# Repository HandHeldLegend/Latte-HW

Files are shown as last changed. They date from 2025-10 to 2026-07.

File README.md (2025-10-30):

# Latte Project
This is the official Github page for project Latte from Hand Held Legend.

## Software and PCB License
<br />This firmware and PCB model are licensed under a <a rel="license" href="http://creativecommons.org/licenses/by-nc-sa/3.0/">Creative Commons Attribution-NonCommercial-ShareAlike 3.0 Unported License</a>.

## 3D Models License

<br />The 3D shell, buttons, and other associated models are licensed under a <a rel="license" href="http://creativecommons.org/licenses/by/4.0/">Creative Commons Attribution 4.0 International License</a>.

## Attributions

Resources Cross-Referenced for shell shape:
- 3D Scans by Wesk

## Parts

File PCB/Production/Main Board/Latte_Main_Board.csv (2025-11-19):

Reference | Qty | Value | Datasheet | Footprint | Manufacturer | MPN | DNP | LCSC | Description
C3,C4,C5,C6,C7,C8,C17,C18,C19,C29,C30,C31,C32,C33,C34,C35,C36,C37,C38 | 19 | 100n | ~ | Capacitor_SMD:C_0201_0603Metric | muRata | GRM033R61A104KE15D |  | C76934 | 10V 100nF X5R ±10% 0201 Ceramic Capacitors RoHS
C23,C39,C40,C41 | 4 | 4.7u | ~ | Capacitor_SMD:C_0402_1005Metric | Samsung Electro-Mechanics | CL05A475KP5NRNC |  | C368809 | 10V 4.7uF X5R ±10% 0402 Ceramic Capacitors RoHS
L1 | 1 | 3.3u | https://abracon.com/datasheets/AOTA-B201610S3R3-101-T.pdf | hhl:L_pol_2016 | Abraco LLC | AOTA-B201610S3R3-101-T |  | C42411119 | 0806 POLARIZED Fixed Inductors RoHS
R11 | 1 | 33 | ~ | Resistor_SMD:R_0201_0603Metric | YAGEO | RC0201FR-0733RL |  | C295794 | Resistor
SW1,SW2,SW3,SW4,SW5,SW6,SW7,SW8 | 8 | SW_Push | https://www.lcsc.com/datasheet/C221725.pdf | hhl:KSC-TE | C&K | KSC201J LFS |  | C221725 | Soft 160gf actuator, 3.5mm height tactile button IP67
SW9 | 1 | 1TS026A-1000-0550 | https://datasheet.lcsc.com/lcsc/2201131300_HYP--Hongyuan-Precision-1TS026A-1000-0550-CT_C913778.pdf | hhl:1TS026A-1000-0550 |  | 1TS026A-1000-0550 |  | C913778 | 50mA 2.6mm 100MΩ 200,000 Times 12V 100gf 1.6mm 0.55mm Round Button Standing paste SPST SMD,1.6x2.6mm Tactile Switches ROHS
U1,U3,U6,U7,U8,U9,U10,U11 | 8 | HAL4395 | https://www.lcsc.com/datasheet/C49165022.pdf | hhl:SOT-23-5L | Hallwee | HAL4395SO5 |  | C49165022 | SOT-23-5L Linear, Compass (ICs) ROHS
U2 | 1 | RP2350_80QFN |  | hhl:RP2350-QFN-80-1EP_10x10_P0.4mm_EP3.4x3.4mm_ThermalVias | Raspberry Pi | RP2354B |  | C39843328 | QFN-80-EP(10x10) Microcontrollers RoHS
R1,R15,R26,R27 | 4 | 1k | ~ | Resistor_SMD:R_0201_0603Metric | YAGEO | RC0201FR-071KL |  | C138165 | Resistor
C1,C2 | 2 | 15pF | ~ | Capacitor_SMD:C_0402_1005Metric | YAGEO | CC0402FRNPO9BN150 |  | C326803 | Unpolarized capacitor
C9,C10,C24,C25,C26,C27 | 6 | 100nF | ~ | Capacitor_SMD:C_0201_0603Metric | Samsung Electro-Mechanics | CL03A104KQ3NNNC |  | C160831 | Unpolarized capacitor
C11,C12,C13,C14 | 4 | 1uF | ~ | Capacitor_SMD:C_0201_0603Metric | Murata Electronics | GRM033R60J105KEA2D |  | C76929 | Unpolarized capacitor
D1,D2,D3,D4,D5,D6 | 6 | M7C | ~ | Diode_SMD:D_SOD-523 | LGE | B5819WT |  | C5364321 | Schottky diode
J1,J2 | 2 | SM02B-SURS-TF_LF__SN_ |  | hhl:JST_SM02B-SURS-TF_LF__SN_ | JST | SM02B-SURS-TF(LF)(SN) |  | C566239 | HD Rumble Connector
J3,J5 | 2 | Molex 505110-0892 | ~ | hhl:5051100892 | MOLEX | 505110-0892 |  | C5902847 | Generic connector, single row, 01x08, script generated
J4,J6 | 2 | Molex 505110-0592 | ~ | hhl:5051100592 | MOLEX | 505110-0592 |  | C3168457 | Generic connector, single row, 01x05, script generated
J9 | 1 | Molex 505110-1792 | ~ | hhl:5051101792 | MOLEX | 505110-1792 |  | C6819458 | Generic connector, single row, 01x17, script generated
Q1,Q2 | 2 | MMBT2222A | https://assets.nexperia.com/documents/data-sheet/MMBT2222A.pdf | Package_TO_SOT_SMD:SOT-23 | JSMSEMI | MMBT2222A |  | C916372 | 600mA Ic, 40V Vce, NPN Transistor, SOT-23
R2,R7,R8,R12,R13,R14,R16,R17,R18,R19,R20,R21,R22,R23,R24,R25,R28,R29,R30,R31 | 20 | 100R | ~ | Resistor_SMD:R_0201_0603Metric | YAGEO | RC0201FR-07100RL |  | C77623 | Resistor
R3,R4 | 2 | 27R | ~ | Resistor_SMD:R_0201_0603Metric | YAGEO | RC0201FR-0727RL |  | C273268 | Resistor
R5,R6 | 2 | 10k | ~ | Resistor_SMD:R_0201_0603Metric | YAGEO | RC0201FR-0710KL |  | C106225 | Resistor
R9,R10 | 2 | 10R | ~ | Resistor_SMD:R_0201_0603Metric | YAGEO | RC0201FR-0710RL |  | C106226 | Resistor
RGB1,RGB2,RGB3,RGB4,RGB5,RGB6,RGB7,RGB8,RGB9,RGB10,RGB11,RGB12 | 12 | SK6805-EC-10 | https://cdn-shop.adafruit.com/product-files/5849/SK6805-EC10-000_REV.01_EN.pdf | hhl:SK6805-EC-10 | OPSCO Optoelectronics | SK6805-EC-10 |  | C22394946 | RGB LED
U4,U5 | 2 | ST_LSM6 |  | hhl:LGA14 | STMicroelectronics | LSM6DSLTR |  | C126672 | Accelerometer gyroscope LGA-14(2.5x3) Accelerometers ROHS
Y1 | 1 | ABM8-272-T3 | ~ | Crystal:Crystal_SMD_3225-4Pin_3.2x2.5mm | Abracon LLC | ABM8-272-T3 |  | C20625731 | Four pin crystal, GND on pins 2 and 4

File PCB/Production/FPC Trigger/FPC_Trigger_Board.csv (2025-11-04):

Reference | Qty | Value | Datasheet | Footprint | Manufacturer | MPN | LCSC | DNP
C1,C2,C3,C4 | 4 | 100n | ~ | Capacitor_SMD:C_0201_0603Metric | muRata | GRM033R61A104KE15D | C76934
J1,J2 | 2 | Conn_01x05_Pin | ~ | hhl:505110-0592 Ribbon |  |  |  | DNP
U1,U2,U3,U4 | 4 | HAL4395 | https://www.lcsc.com/datasheet/C49165022.pdf | Package_TO_SOT_SMD:SOT-23-5 | Hallwee | HAL4395SO5 | C49165022

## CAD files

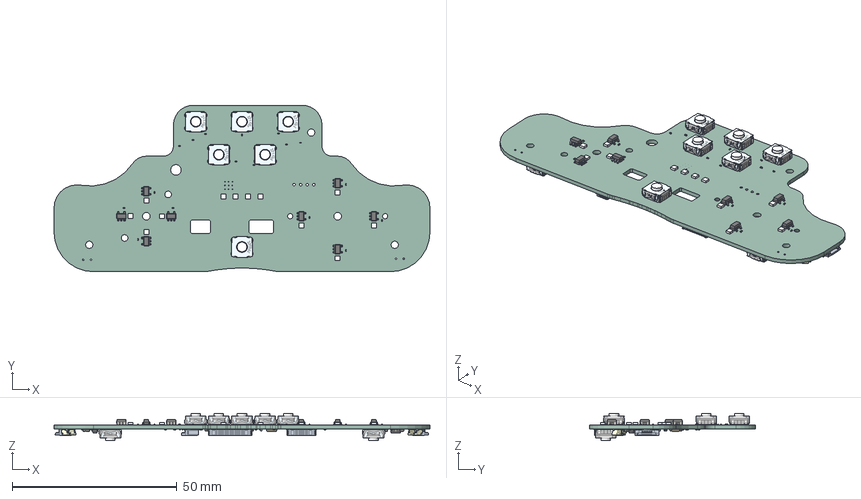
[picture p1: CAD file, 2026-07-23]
3D/Latte_Main_Board.step
114.0 x 50.5 x 8.33 mm
SK6805-EC15 x 12
R_0201_0603Metric x 31
C_0201_0603Metric x 29
KSC2TE01JLFS_PART1 x 8
SOT-23-5 x 8
SOT-23 x 2
D_SOD-523 x 6
C_0402_1005Metric x 6
SM02B-SURS-TF(LF)(SN) x 2
Crystal_SMD_3225-4Pin_3.2x2.5mm
Latte_Main_Board_PCB

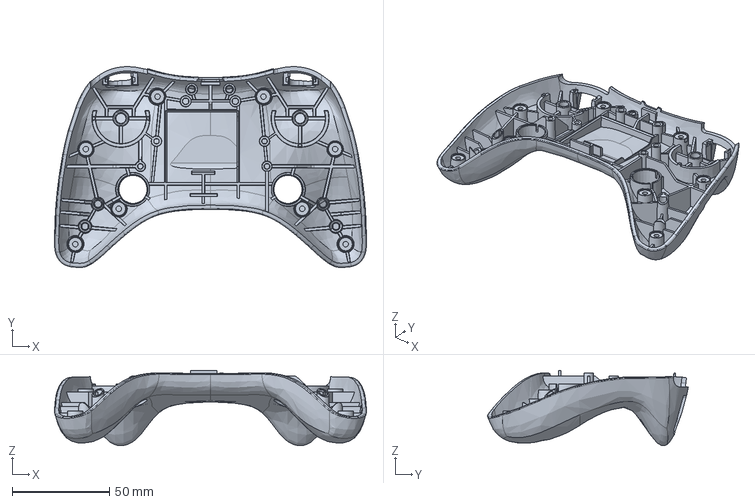
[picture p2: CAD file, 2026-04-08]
3D/STEP/Acrylic/PRO_LOWERSHELL.step
160.2 x 103.1 x 38.7 mm

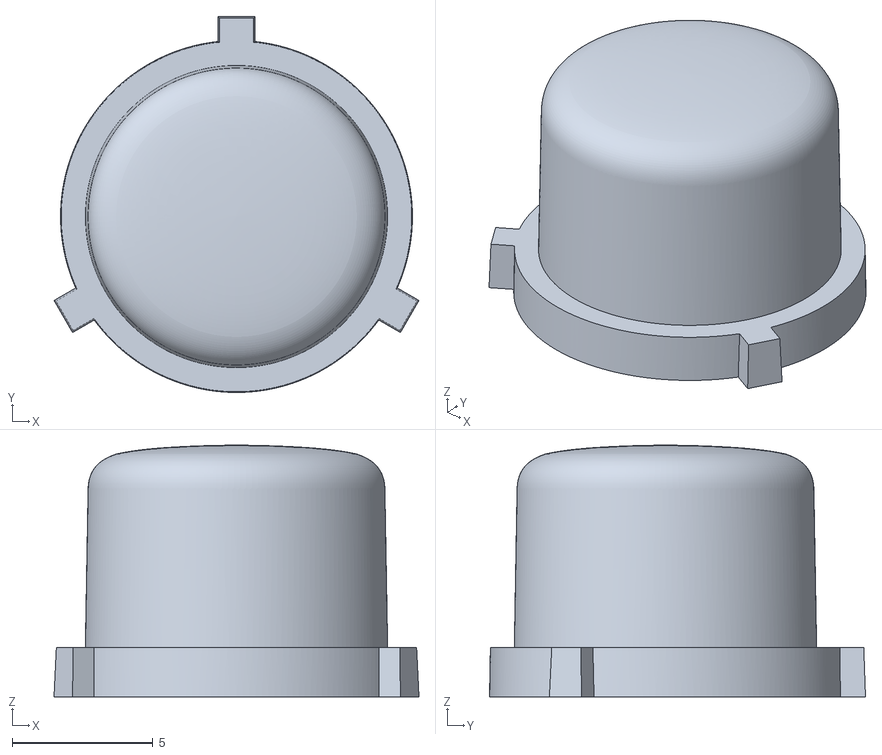
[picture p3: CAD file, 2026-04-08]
3D/STL/SEWN.stl
13.0 x 13.4 x 8.95

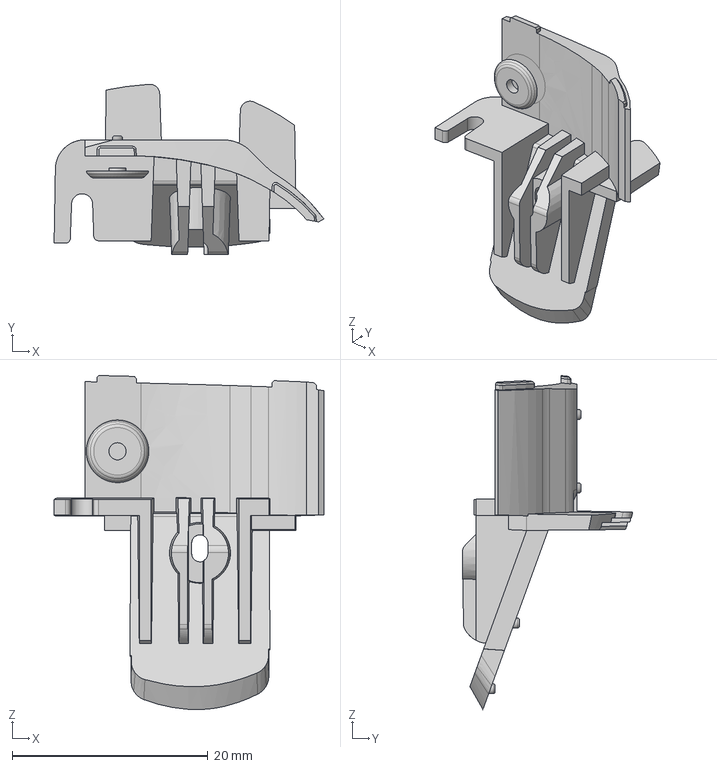
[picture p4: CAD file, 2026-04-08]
3D/STEP/Acrylic/PRO_RSUPPORT.step
27.5 x 17.4 x 34.1 mm

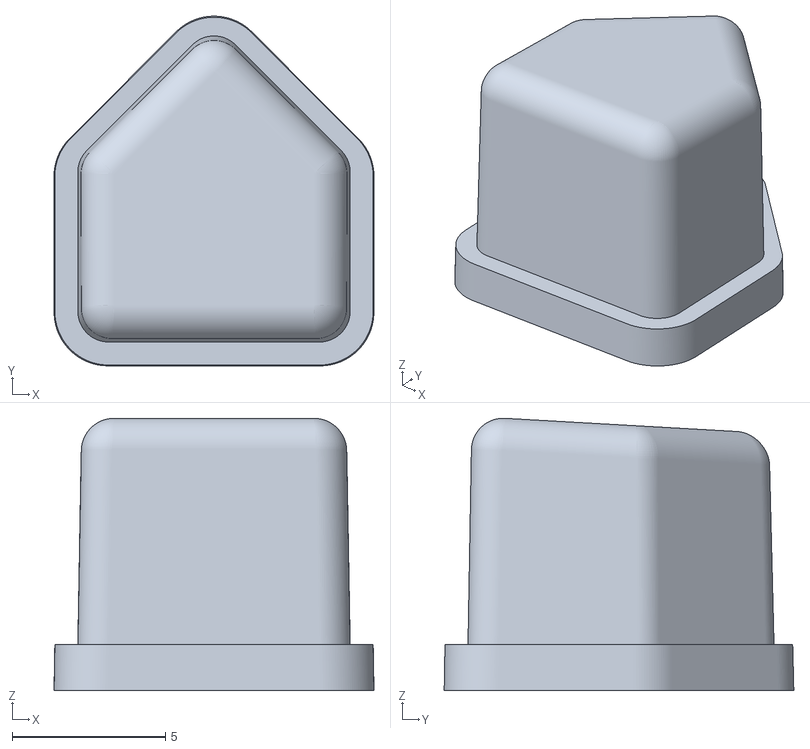
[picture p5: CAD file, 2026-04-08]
3D/STL/DPAD.stl
10.4 x 11.4 x 8.88

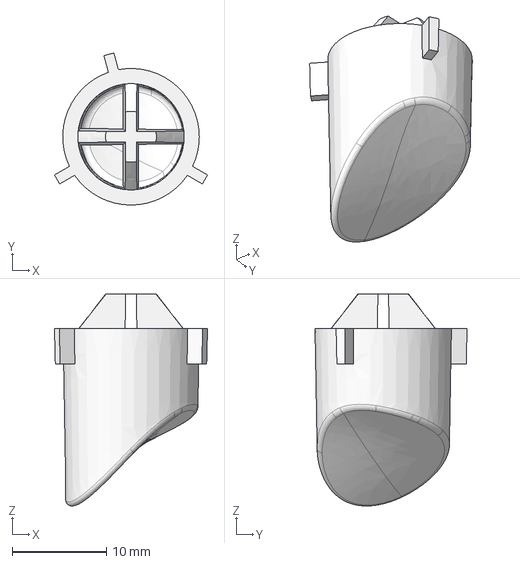
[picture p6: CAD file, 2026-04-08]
3D/STEP/Acrylic/PRO_GRIPBUTTONL.step
16.2 x 16.1 x 22.5 mm

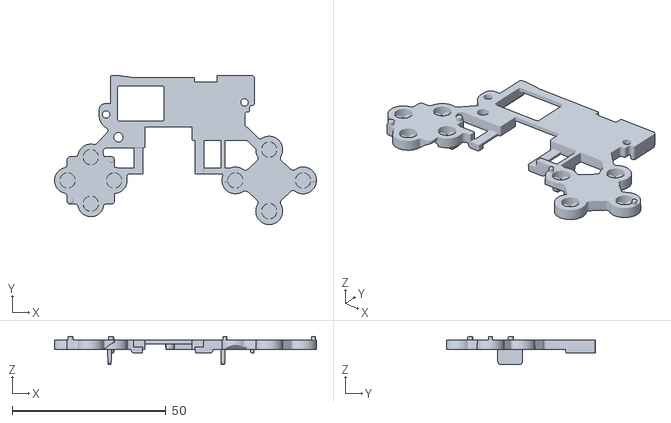
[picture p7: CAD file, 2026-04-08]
3D/STL/MIDFRAME.stl
85.2 x 48.5 x 9.21

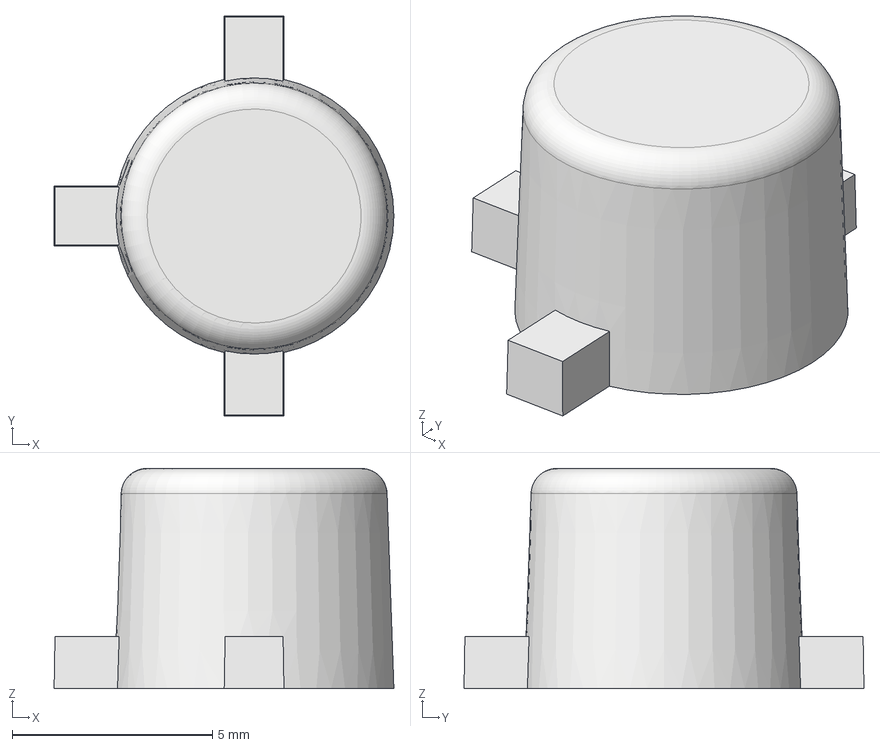
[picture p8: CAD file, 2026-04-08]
3D/STEP/Acrylic/PRO_MENU.step
8.49 x 9.99 x 5.50 mm

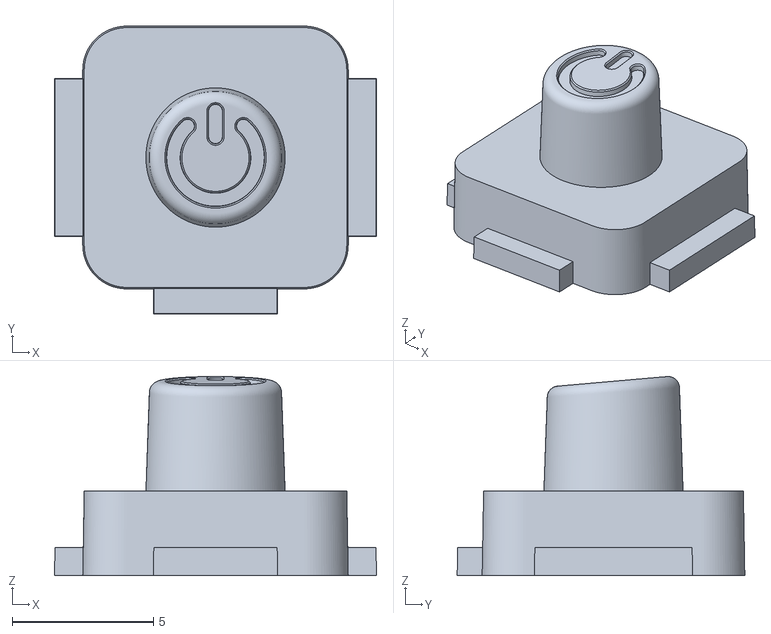
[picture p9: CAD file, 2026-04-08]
3D/STL/POWERBUTTON.stl
11.4 x 10.2 x 7.05

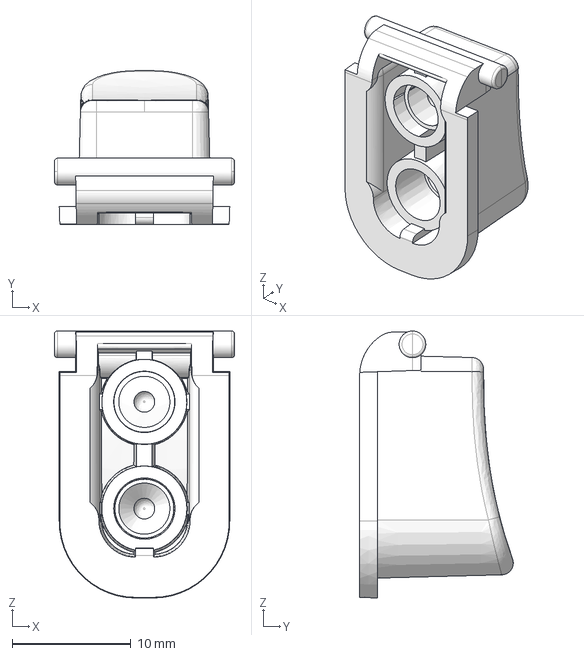
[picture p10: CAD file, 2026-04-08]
3D/STEP/Acrylic/PRO_TRIGGER.step
15.2 x 12.9 x 22.5 mm

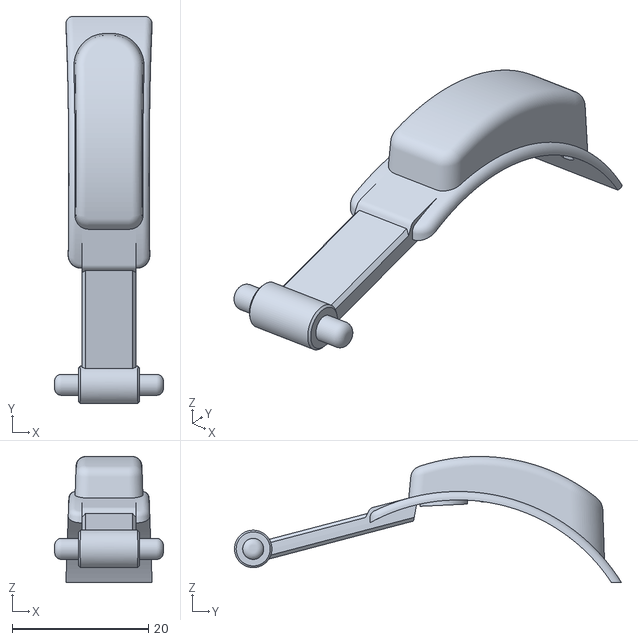
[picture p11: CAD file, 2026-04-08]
3D/STL/SHOULDER.stl
16.0 x 56.9 x 18.5

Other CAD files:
3D/STEP/Acrylic/PRO_DPAD.step
3D/STL/LSUPPORT.stl
3D/STEP/Acrylic/PRO_LSUPPORT.step
3D/STL/GRIPBUTTONR.stl
3D/STEP/Acrylic/PRO_GRIPBUTTONR.step
3D/STL/RSUPPORT.stl
3D/STEP/Acrylic/PRO_POWERBUTTON.step
3D/STEP/Acrylic/PRO_MIDFRAME.step
3D/STEP/Acrylic/PRO_PLAYERLIGHTS.step
3D/STEP/Acrylic/PRO_SEWN.step
3D/STEP/Acrylic/PRO_SHOULDER.step
3D/STEP/POM/ScrewPlateOctagon.step
3D/STEP/POM/ScrewPlateRound.step
3D/STL/GRIPBUTTONL.stl
3D/STL/MENU.stl
3D/STL/PLAYERLIGHTS.stl
3D/STL/SCREWPLATEOCTO.stl
3D/STL/SCREWPLATEROUND.stl
3D/STL/TRIGGER.stl

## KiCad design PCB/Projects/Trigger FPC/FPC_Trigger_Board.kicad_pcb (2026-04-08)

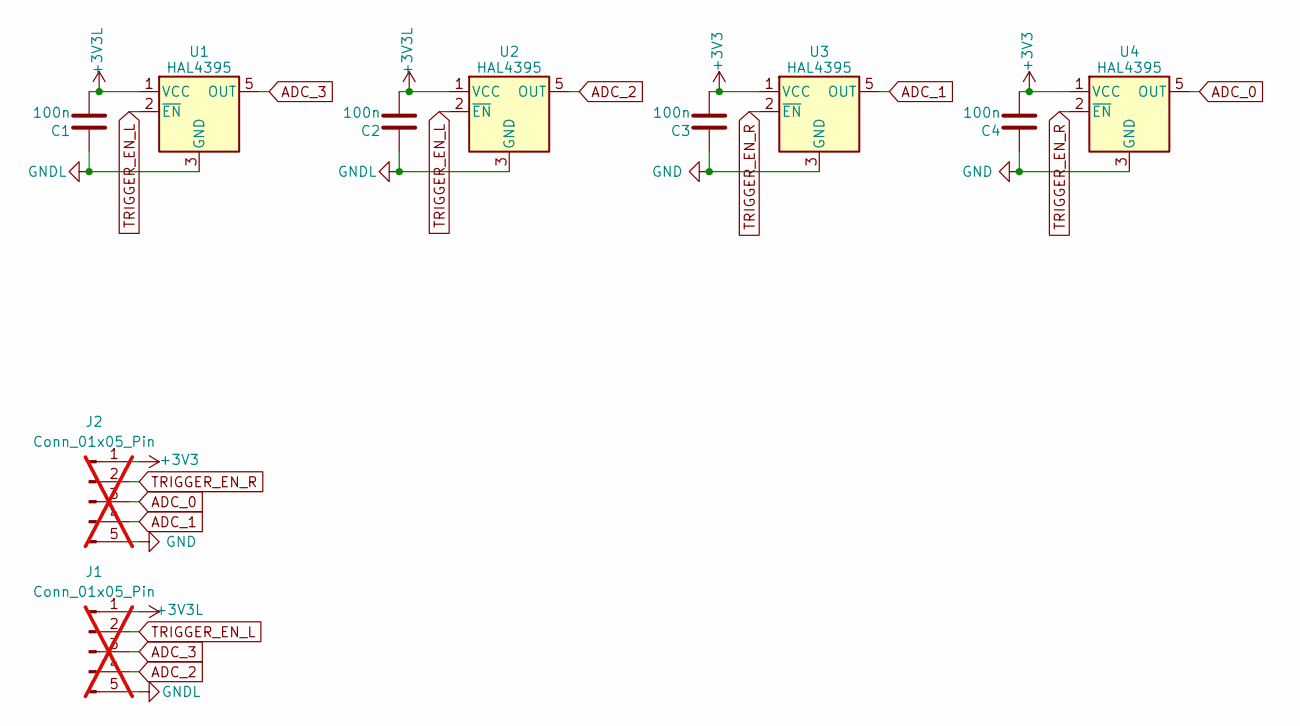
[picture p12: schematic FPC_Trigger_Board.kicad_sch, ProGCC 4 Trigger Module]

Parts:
C1, C2, C3, C4: 100n; C_0201_0603Metric; MPN GRM033R61A104KE15D; LCSC C76934
J1, J2: Conn_01x05_Pin; 505110-0592 Ribbon; not fitted
U1, U2, U3, U4: HAL4395; SOT-23-5L; MPN HAL4395SO5; LCSC C49165022

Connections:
+3V3: C3.2, C4.2, J2.1, U3.1 (VCC), U4.1 (VCC)
+3V3L: C1.2, C2.2, J1.1, U1.1 (VCC), U2.1 (VCC)
ADC_0: J2.3, U4.5 (OUT)
ADC_1: J2.4, U3.5 (OUT)
ADC_2: J1.4, U2.5 (OUT)
ADC_3: J1.3, U1.5 (OUT)
GND: C3.1, C4.1, J2.5, U3.3 (GND), U4.3 (GND)
GNDL: C1.1, C2.1, J1.5, U1.3 (GND), U2.3 (GND)
TRIGGER_EN_L: J1.2, U1.2 (~EN), U2.2 (~EN)
TRIGGER_EN_R: J2.2, U3.2 (~EN), U4.2 (~EN)

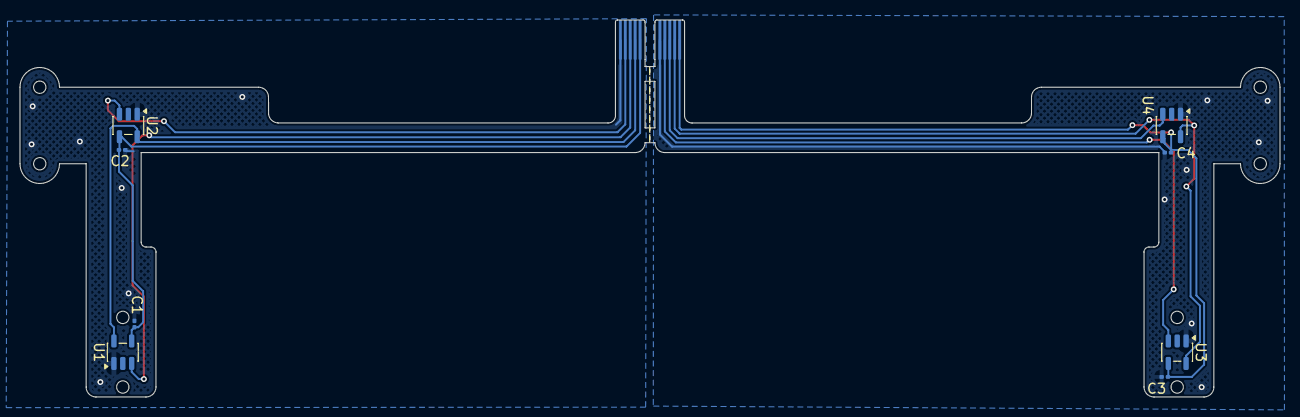
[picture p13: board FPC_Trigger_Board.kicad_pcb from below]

Board: 2 copper layers, 127.6 x 38.2 mm, 10 parts (8 on the bottom side), 10 nets.

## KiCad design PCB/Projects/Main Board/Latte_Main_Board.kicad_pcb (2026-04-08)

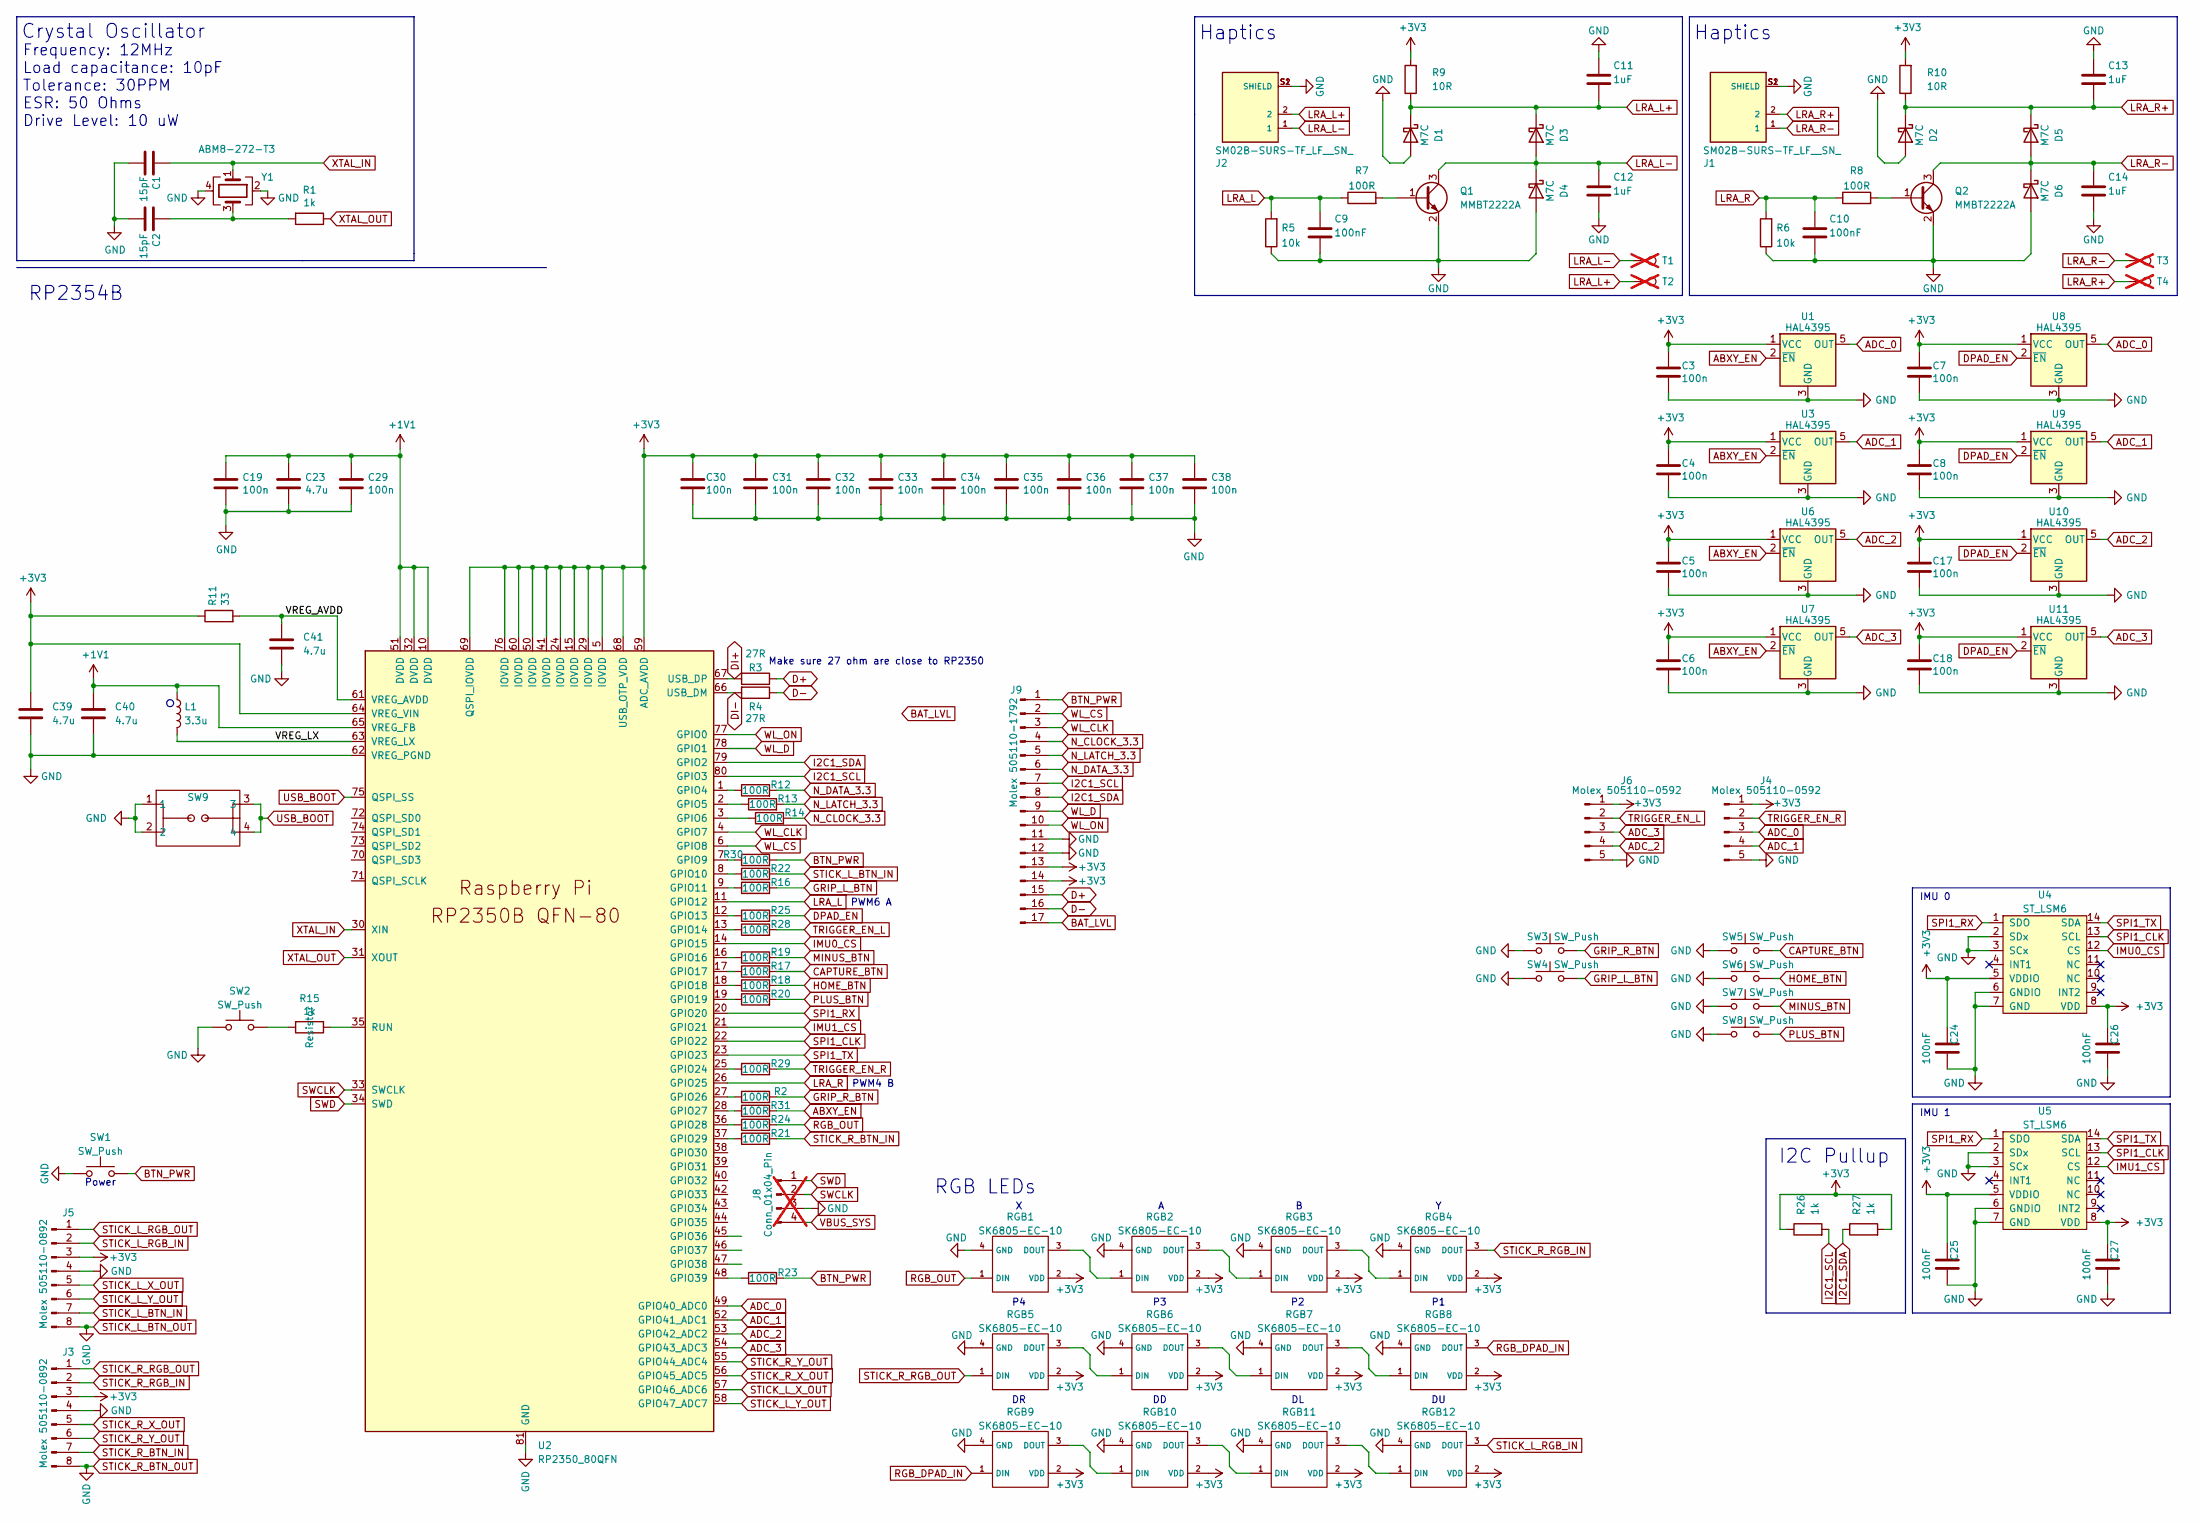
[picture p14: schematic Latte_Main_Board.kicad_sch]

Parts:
C1, C2: 15pF; C_0402_1005Metric; MPN CC0402FRNPO9BN150; LCSC C326803
C3, C4, C5, C6, C7, C8, C17, C18, C19, C29, C30, C31, C32, C33, C34, C35, C36, C37, C38: 100n; C_0201_0603Metric; MPN GRM033R61A104KE15D; LCSC C76934
C9, C10, C24, C25, C26, C27: 100nF; C_0201_0603Metric; MPN CL03A104KQ3NNNC; LCSC C160831
C11, C12, C13, C14: 1uF; C_0201_0603Metric; MPN GRM033R60J105KEA2D; LCSC C76929
C23, C39, C40, C41: 4.7u; C_0402_1005Metric; MPN CL05A475KP5NRNC; LCSC C368809
D1, D2, D3, D4, D5, D6: M7C; D_SOD-523; MPN B5819WT; LCSC C5364321
J1, J2: SM02B-SURS-TF_LF__SN_; JST_SM02B-SURS-TF_LF__SN_; PARTREV N/A; LCSC C566239
J3, J5: Molex 505110-0892; 5051100892; MPN 505110-0892; LCSC C5902847
J4, J6: Molex 505110-0592; 5051100592; MPN 505110-0592; LCSC C3168457
J8: Conn_01x04_Pin; PinHeader_1x04_P2.00mm_Vertical; not fitted
J9: Molex 505110-1792; 5051101792; MPN 505110-1792; LCSC C6819458
L1: 3.3u; L_pol_2016; MPN AOTA-B201610S3R3-101-T; LCSC C42411119
Q1, Q2: MMBT2222A; SOT-23; MPN MMBT2222A; LCSC C916372
R1, R15, R26, R27: 1k; R_0201_0603Metric; MPN RC0201FR-071KL; LCSC C138165
R2, R7, R8, R12, R13, R14, R16, R17, R18, R19, R20, R21, R22, R23, R24, R25, R28, R29, R30, R31: 100R; R_0201_0603Metric; MPN RC0201FR-07100RL; LCSC C77623
R3, R4: 27R; R_0201_0603Metric; MPN RC0201FR-0727RL; LCSC C273268
R5, R6: 10k; R_0201_0603Metric; MPN RC0201FR-0710KL; LCSC C106225
R9, R10: 10R; R_0201_0603Metric; MPN RC0201FR-0710RL; LCSC C106226
R11: 33; R_0201_0603Metric; MPN RC0201FR-0733RL; LCSC C295794
RGB1, RGB2, RGB3, RGB4, RGB5, RGB6, RGB7, RGB8, RGB9, RGB10, RGB11, RGB12: SK6805-EC-10; MPN SK6805-EC-10; LCSC C22394946
SW1, SW2, SW3, SW4, SW5, SW6, SW7, SW8: SW_Push; KSC-TE; MPN KSC201J LFS; LCSC C221725
SW9: 1TS026A-1000-0550; MPN 1TS026A-1000-0550; LCSC C913778
T1, T2, T3, T4: PinHeader_1x01_P1.00mm_Vertical; not fitted
U1, U3, U6, U7, U8, U9, U10, U11: HAL4395; SOT-23-5L; MPN HAL4395SO5; LCSC C49165022
U2: RP2350_80QFN; RP2350-QFN-80-1EP_10x10_P0.4mm_EP3.4x3.4mm_ThermalVias; MPN RP2354B; LCSC C39843328
U4, U5: ST_LSM6; LGA14; MPN LSM6DSLTR; LCSC C126672
Y1: ABM8-272-T3; Crystal_SMD_3225-4Pin_3.2x2.5mm; MPN ABM8-272-T3; LCSC C20625731

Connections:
+1V1: C19.1, C23.1, C29.1, C40.1, L1.1, U2.10 (DVDD), U2.32 (DVDD), U2.51 (DVDD), U2.65 (VREG_FB)
+3V3: C3.1, C4.1, C5.1, C6.1, C7.1, C8.1, C17.1, C18.1, C24.2, C25.2, C26.2, C27.2, C30.1, C31.1, C32.1, C33.1, C34.1, C35.1, C36.1, C37.1, C38.1, C39.1, J3.3, J4.1, J5.3, J6.1, J9.13, J9.14, R9.2, R10.2, R11.1, R26.1, R27.2, RGB1.2 (VDD), RGB2.2 (VDD), RGB3.2 (VDD), RGB4.2 (VDD), RGB5.2 (VDD), RGB6.2 (VDD), RGB7.2 (VDD), RGB8.2 (VDD), RGB9.2 (VDD), RGB10.2 (VDD), RGB11.2 (VDD), RGB12.2 (VDD), U1.1 (VCC), U2.5 (IOVDD), U2.15 (IOVDD), U2.24 (IOVDD), U2.29 (IOVDD), U2.41 (IOVDD), U2.50 (IOVDD), U2.59 (ADC_AVDD), U2.60 (IOVDD), U2.64 (VREG_VIN), U2.68 (USB_OTP_VDD), U2.69 (QSPI_IOVDD), U2.76 (IOVDD), U3.1 (VCC), U4.5 (VDDIO), U4.8 (VDD), U5.5 (VDDIO), U5.8 (VDD), U6.1 (VCC), U7.1 (VCC), U8.1 (VCC), U9.1 (VCC), U10.1 (VCC), U11.1 (VCC)
/VREG_AVDD: C41.1, R11.2, U2.61 (VREG_AVDD)
/VREG_LX: L1.2, U2.63 (VREG_LX)
ABXY_EN: R31.2, U1.2 (~EN), U3.2 (~EN), U6.2 (~EN), U7.2 (~EN)
ADC_0: J4.3, U1.5 (OUT), U2.49 (GPIO40_ADC0), U8.5 (OUT)
ADC_1: J4.4, U2.52 (GPIO41_ADC1), U3.5 (OUT), U9.5 (OUT)
ADC_2: J6.4, U2.53 (GPIO42_ADC2), U6.5 (OUT), U10.5 (OUT)
ADC_3: J6.3, U2.54 (GPIO43_ADC3), U7.5 (OUT), U11.5 (OUT)
BAT_LVL: J9.17
BTN_PWR: J9.1, R23.2, R30.2, SW1.2
CAPTURE_BTN: R17.2, SW5.2
D+: J9.15, R3.1
D-: J9.16, R4.1
DI+: R3.2, U2.67 (USB_DP)
DI-: R4.2, U2.66 (USB_DM)
DPAD_EN: R25.2, U8.2 (~EN), U9.2 (~EN), U10.2 (~EN), U11.2 (~EN)
GRIP_L_BTN: R16.2, SW4.2
GRIP_R_BTN: R2.2, SW3.2
HOME_BTN: R18.2, SW6.2
I2C1_SCL: J9.7, R26.2, U2.80 (GPIO3)
I2C1_SDA: J9.8, R27.1, U2.79 (GPIO2)
IMU0_CS: U2.14 (GPIO15), U4.12 (CS)
IMU1_CS: U2.21 (GPIO21), U5.12 (CS)
LRA_L: C9.1, R5.2, R7.1, U2.11 (GPIO12)
LRA_L+: C11.2, D1.1 (K), D3.1 (K), J2.2, R9.1, T2.1
LRA_L-: C12.1, D3.2 (A), D4.1 (K), J2.1, Q1.3 (C), T1.1
LRA_R: C10.1, R6.2, R8.1, U2.26 (GPIO25)
LRA_R+: C13.2, D2.1 (K), D5.1 (K), J1.2, R10.1, T4.1
LRA_R-: C14.1, D5.2 (A), D6.1 (K), J1.1, Q2.3 (C), T3.1
MINUS_BTN: R19.2, SW7.2
N_CLOCK_3.3: J9.4, R14.2
N_DATA_3.3: J9.6, R12.2
N_LATCH_3.3: J9.5, R13.2
unnamed: C2.1, R1.2, Y1.3
unnamed: Q1.1 (B), R7.2
unnamed: Q2.1 (B), R8.2
unnamed: R15.2, SW2.2
unnamed: RGB1.3 (DOUT), RGB2.1 (DIN)
unnamed: RGB2.3 (DOUT), RGB3.1 (DIN)
unnamed: RGB3.3 (DOUT), RGB4.1 (DIN)
unnamed: RGB5.3 (DOUT), RGB6.1 (DIN)
unnamed: RGB6.3 (DOUT), RGB7.1 (DIN)
unnamed: RGB7.3 (DOUT), RGB8.1 (DIN)
unnamed: RGB9.3 (DOUT), RGB10.1 (DIN)
unnamed: RGB10.3 (DOUT), RGB11.1 (DIN)
unnamed: RGB11.3 (DOUT), RGB12.1 (DIN)
unnamed: R12.1, U2.1 (GPIO4)
unnamed: R13.1, U2.2 (GPIO5)
unnamed: R14.1, U2.3 (GPIO6)
unnamed: R30.1, U2.7 (GPIO9)
unnamed: R22.1, U2.8 (GPIO10)
unnamed: R16.1, U2.9 (GPIO11)
unnamed: R25.1, U2.12 (GPIO13)
unnamed: R28.1, U2.13 (GPIO14)
unnamed: R19.1, U2.16 (GPIO16)
unnamed: R17.1, U2.17 (GPIO17)
unnamed: R18.1, U2.18 (GPIO18)
unnamed: R20.1, U2.19 (GPIO19)
unnamed: R29.1, U2.25 (GPIO24)
unnamed: R2.1, U2.27 (GPIO26)
unnamed: R31.1, U2.28 (GPIO27)
unnamed: R24.1, U2.36 (GPIO28)
unnamed: R21.1, U2.37 (GPIO29)
unnamed: R23.1, U2.48 (GPIO39)
unnamed: R15.1, U2.35 (RUN)
PLUS_BTN: R20.2, SW8.2
RGB_DPAD_IN: RGB8.3 (DOUT), RGB9.1 (DIN)
RGB_OUT: R24.2, RGB1.1 (DIN)
SPI1_CLK: U2.22 (GPIO22), U4.13 (SCL), U5.13 (SCL)
SPI1_RX: U2.20 (GPIO20), U4.1 (SDO), U5.1 (SDO)
SPI1_TX: U2.23 (GPIO23), U4.14 (SDA), U5.14 (SDA)
STICK_L_BTN_IN: J5.7, R22.2
STICK_L_BTN_OUT: C1.2, C2.2, C3.2, C4.2, C5.2, C6.2, C7.2, C8.2, C9.2, C10.2, C11.1, C12.2, C13.1, C14.2, C17.2, C18.2, C19.2, C23.2, C24.1, C25.1, C26.1, C27.1, C29.2, C30.2, C31.2, C32.2, C33.2, C34.2, C35.2, C36.2, C37.2, C38.2, C39.2, C40.2, C41.2, D1.2 (A), D2.2 (A), D4.2 (A), D6.2 (A), J1.S1 (SHIELD), J1.S2 (SHIELD), J2.S1 (SHIELD), J2.S2 (SHIELD), J3.4, J3.8, J4.5, J5.4, J5.8, J6.5, J8.3, J9.11, J9.12, Q1.2 (E), Q2.2 (E), R5.1, R6.1, RGB1.4 (GND), RGB2.4 (GND), RGB3.4 (GND), RGB4.4 (GND), RGB5.4 (GND), RGB6.4 (GND), RGB7.4 (GND), RGB8.4 (GND), RGB9.4 (GND), RGB10.4 (GND), RGB11.4 (GND), RGB12.4 (GND), SW1.1, SW2.1, SW3.1, SW4.1, SW5.1, SW6.1, SW7.1, SW8.1, SW9.1, SW9.2, U1.3 (GND), U2.62 (VREG_PGND), U2.81 (GND), U3.3 (GND), U4.2 (SDx), U4.3 (SCx), U4.6 (GNDIO), U4.7 (GND), U5.2 (SDx), U5.3 (SCx), U5.6 (GNDIO), U5.7 (GND), U6.3 (GND), U7.3 (GND), U8.3 (GND), U9.3 (GND), U10.3 (GND), U11.3 (GND), Y1.2, Y1.4
STICK_L_RGB_IN: J5.2, RGB12.3 (DOUT)
STICK_L_RGB_OUT: J5.1
STICK_L_X_OUT: J5.5, U2.57 (GPIO46_ADC6)
STICK_L_Y_OUT: J5.6, U2.58 (GPIO47_ADC7)
STICK_R_BTN_IN: J3.7, R21.2
STICK_R_RGB_IN: J3.2, RGB4.3 (DOUT)
STICK_R_RGB_OUT: J3.1, RGB5.1 (DIN)
STICK_R_X_OUT: J3.5, U2.56 (GPIO45_ADC5)
STICK_R_Y_OUT: J3.6, U2.55 (GPIO44_ADC4)
SWCLK: J8.2, U2.33 (SWCLK)
SWD: J8.1, U2.34 (SWD)
TRIGGER_EN_L: J6.2, R28.2
TRIGGER_EN_R: J4.2, R29.2
USB_BOOT: SW9.3, SW9.4, U2.75 (QSPI_SS)
VBUS_SYS: J8.4
WL_CLK: J9.3, U2.4 (GPIO7)
WL_CS: J9.2, U2.6 (GPIO8)
WL_D: J9.9, U2.78 (GPIO1)
WL_ON: J9.10, U2.77 (GPIO0)
XTAL_IN: C1.1, U2.30 (XIN), Y1.1
XTAL_OUT: R1.1, U2.31 (XOUT)

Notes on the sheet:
Power
PWM6 A
RP2354B
Haptics
RGB LEDs
Crystal Oscillator
IMU 1
PWM4 B
IMU 0
I2C Pullup
Frequency: 12MHz Load capacitance: 10pF Tolerance: 30PPM ESR: 50 Ohms Drive Level: 10 uW
Make sure 27 ohm are close to RP2350

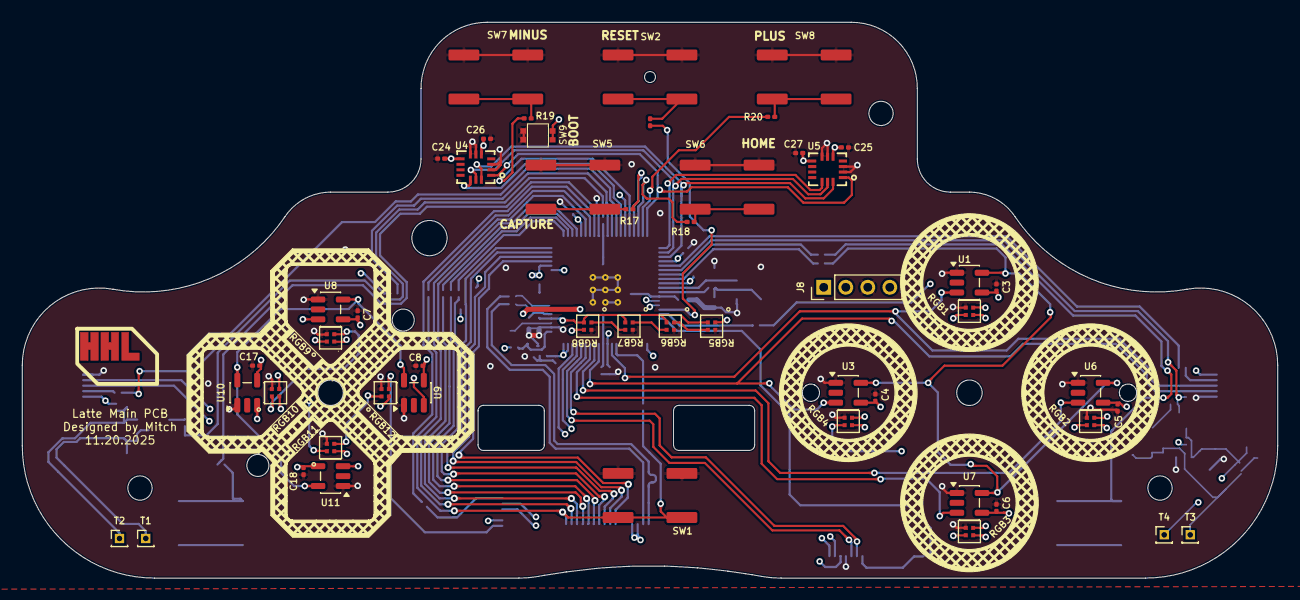
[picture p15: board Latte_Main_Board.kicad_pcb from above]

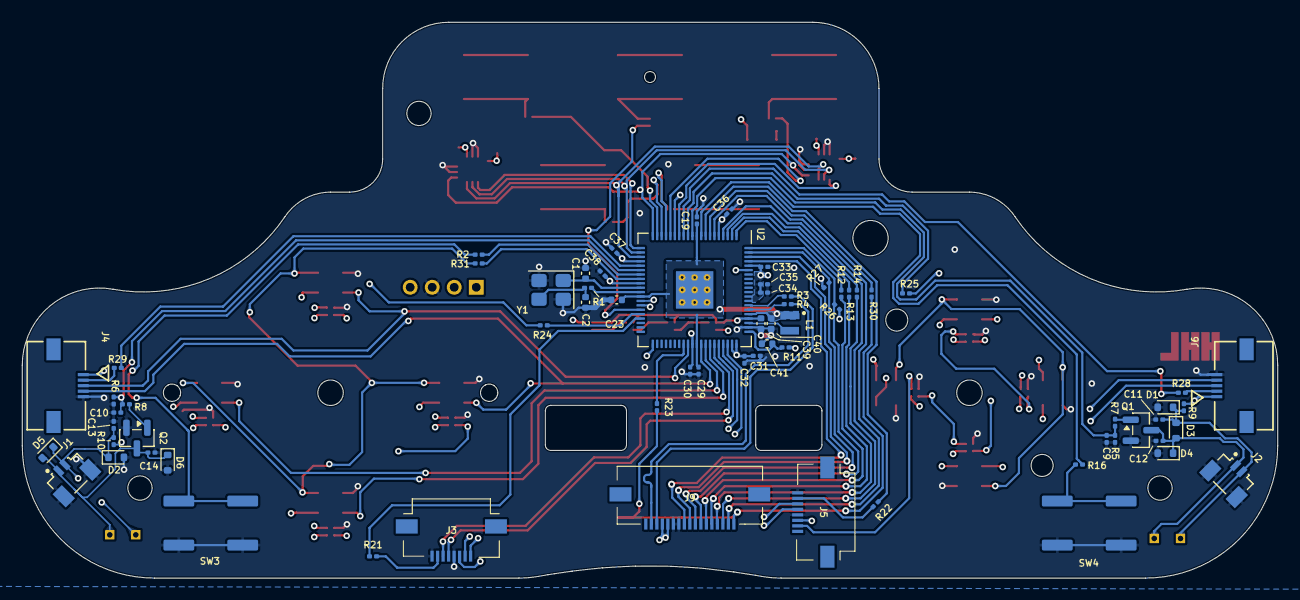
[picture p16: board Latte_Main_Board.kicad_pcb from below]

Board: 4 copper layers, 114.0 x 50.5 mm, 120 parts (69 on the bottom side), 92 nets.

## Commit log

2025-10-30 Routing updates
    [Latte_Main_Board.kicad_pcb, Latte_Main_Board.kicad_sch]
2025-11-02 fun outline
    [Latte_Main_Board.kicad_pcb]
2025-11-04 Prod 1
    [FPC_Trigger_Board-B_Cu.gbr, FPC_Trigger_Board-B_Mask.gbr, FPC_Trigger_Board-B_Paste.gbr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]
2025-11-12 3D Files Initial STLs
    [DPAD.stl, GRIPBUTTONL.stl, GRIPBUTTONR.stl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]
2025-11-12 Fix joystick internal shaft diameter
2025-11-18 STL Updates
    - DPAD and SEWN buttons are modified to have adhesive recesses
    - RSUPPORT and LSUPPORT offset to get out of the way of solder joints
    - TOPSHELL is updated to feature glyphs for menu buttons
    - GRIPBUTTONR and GRIPBUTTONL have a 15 degree shift for one of the alignment nubs to assist with installation ease. Ensures they only fit on one side.
    - LOWERSHELL has been updated to match the changes for the GRIPBUTTON changes
    - LOWERMENU and UPPERMENU have been changed to just be MENU
    [DPAD.stl, GRIPBUTTONL.stl, GRIPBUTTONR.stl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]
2025-11-19 PCB Update
    - Missing BOOT switch added
    [Latte_Main_Board-B_Cu.gbr, Latte_Main_Board-B_Mask.gbr, Latte_Main_Board-B_Paste.gbr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]
2025-11-20 Silkscreen updates
    [Latte_Main_Board.kicad_pcb]
2025-11-20 PCB Updates
    [Latte_Main_Board-B_Cu.gbr, Latte_Main_Board-B_Mask.gbr, Latte_Main_Board-B_Paste.gbr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]
2025-12-12 FPC Fixes
    [FPC_Trigger_Board-B_Cu.gbr, FPC_Trigger_Board-B_Mask.gbr, FPC_Trigger_Board-B_Paste.gbr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]
2025-12-12 3d Updates
    [LSUPPORT.stl, RSUPPORT.stl, TRIGGERV2.stl]
2026-01-03 FPC Board Update
    [FPC_Trigger_Board.kicad_pcb]
